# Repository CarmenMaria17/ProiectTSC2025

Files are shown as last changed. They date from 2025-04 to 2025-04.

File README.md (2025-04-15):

# TSC2025 Project

## Block Diagram



## Brief Description

### Microcontroller
- **ESP32-C6**: Main processor with WiFi/BLE, controls all components

### Display and Storage
- **E-Ink Display**: Minimal power consumption display
- **SD Card**: Electronic book storage
- **64MB Flash Memory**: For firmware and cache

### Power
- **USB-C**: Charging and data transfer
- **Battery charging circuit**: MCP73831 for LiPo battery
- **LiPo Battery**: 3.7V portable power
- **3.3V Regulator**: Voltage stabilizer for ESP32 and sensors

### Sensors
- **BME680**: Temperature and humidity, I2C connection

### Other Components
- **RTC DS3231**: Real-time clock for timekeeping
- **Buttons**: Navigation and control via GPIO

### Interfaces
- **SPI**: Display, SD card, flash memory
- **I2C**: Sensors, RTC
- **GPIO**: Buttons and control

## ESP32-C6 - Pin Allocation

### Communication pins
- **SPI_CLK**: Clock for SPI interface (connected to Flash, SD Card, Display)
- **SPI_MOSI**: Master Out Slave In for SPI
- **SPI_MISO**: Master In Slave Out for SPI
- **SS_SD**: Chip Select for SD Card
- **SS_FLASH**: Chip Select for Flash memory
- **SS_DISP**: Chip Select for E-Ink Display
- **I2C_SCL**: Clock for I2C interface
- **I2C_SDA**: Data line for I2C
- **EPD_DC**: Data/Command for E-Ink display
- **EPD_RST**: Reset for E-Ink display
- **EPD_BUSY**: Status signal from E-Ink display

### Other specific pins
- **RTC_INT**: Interrupt from RTC module
- **VBAT**: Battery power
- **3V3**: 3.3V power
- **GND**: Ground

# Bill of Materials

| Component | Model | Datasheet |
|---|---|---|
| BD5229G-TR | [Model](https://www.digikey.ee/en/models/658502) | [Datasheet](https://www.rohm.com/datasheet?p=BD5229G&dist=Digi-key&media=referral&source=digi-key.com&campaign=Digi-key) |
| ESP32 WROVER 0805 Capacitor | [Model](https://ro.mouser.com/ProductDetail/KYOCERA-AVX/SD0805S020S1R0?qs=jCA%252BPfw4LHbpkAoSnwrdjw%3D%3D) | [Datasheet](https://ro.mouser.com/datasheet/2/40/schottky-3165252.pdf) |
| 112A-TAAR-R03 | [Model](https://www.snapeda.com/parts/112A-TAAR-R03/Attend/view-part/) | [Datasheet](https://www.snapeda.com/parts/112A-TAAR-R03/Attend/datasheet/) |
| 744043680 | [Model](https://ro.mouser.com/ProductDetail/Wurth-Elektronik/744043680?qs=PGXP4M47uW6VkZq%252BkzjrHA%3D%3D) | [Datasheet](https://www.we-online.com/components/products/datasheet/744043680.pdf) |
| LED Chip 0603 | [Model](https://grabcad.com/library/0603-smd-led-1) | [Datasheet](https://www.snapeda.com/parts/KP-1608SURCK/Kingbright/datasheet/) |
| MAX17048G+T10 | [Model](https://www.snapeda.com/parts/MAX17048G+T10/Analog+Devices/view-part/?ref=eda) | [Datasheet](https://www.snapeda.com/parts/MAX17048G+T10/Analog%20Devices/datasheet/) |
| MBR0530 Schottky Diode | [Model](https://www.snapeda.com/parts/MBR0530/Onsemi/view-part/?ref=eda) | [Datasheet](https://www.snapeda.com/parts/MBR0530/ON%20Semiconductor/datasheet/) |
| PGB1010603MR | [Model](https://www.snapeda.com/parts/PGB1010603MR/Littelfuse/view-part/?ref=eda) | [Datasheet](https://www.snapeda.com/parts/PGB1010603MR/Littelfuse%20Inc./datasheet/) |
| QWIIC Connector | [Model](https://www.snapeda.com/parts/PRT-14417/SparkFun/view-part/) | [Datasheet](https://www.snapeda.com/parts/PRT-14417/SparkFun%20Electronics/datasheet/) |
| ESP32 WROVER BME680 Sensor | [Model](https://www.digikey.ro/en/models/7401317) | [Datasheet](https://www.bosch-sensortec.com/media/boschsensortec/downloads/datasheets/bst-bme680-ds001.pdf) |
| FH34SRJ-24S-0.5SH | [Model](https://www.snapeda.com/parts/FH34SRJ-24S-0.5SH(99)/Hirose/view-part/) | [Datasheet](https://www.snapeda.com/parts/FH34SRJ-24S-0.5SH(99)/Hirose%20Connector/datasheet/) |
| Resistor 0402 | [Model](https://componentsearchengine.com/part-view/R0402%201%25%20100%20K%20(RC0402FR-07100KL)/YAGEO) | [Datasheet](https://www.yageo.com/upload/media/product/products/datasheet/rchip/PYu-RC_Group_51_RoHS_L_12.pdf) |
| ESP32 WROVER MCP73831 Power Management | [Model](https://www.snapeda.com/parts/MCP73831T-2ACI/OT/Microchip/view-part/) | [Datasheet](https://www.snapeda.com/parts/MCP73831T-2ACI/OT/Microchip/datasheet/) |
| ESP32C6 Varistor 1812 | [Model](https://www.snapeda.com/parts/RC0603JR-070RL/Yageo/view-part/) | [Datasheet](https://www.snapeda.com/parts/RC0603JR-070RL/Yageo/datasheet/) |
| ESP32C6 WROOM-1-N8 | [Model](https://www.snapeda.com/parts/ESP32-C6-WROOM-1-N8/Espressif+Systems/view-part/?ref=eda) | [Datasheet](https://www.snapeda.com/parts/ESP32-C6-WROOM-1-N8/Espressif%20Systems/datasheet/) |
| Capacitor 0402 | [Model](https://componentsearchengine.com/part-view/CC0402MRX5R5BB106/YAGEO) | [Datasheet](https://componentsearchengine.com/Datasheets/2/CC0402MRX5R5BB106.pdf) |
| SI1308EDL-T1-GE3 MOSFET | [Model](https://www.snapeda.com/parts/SI1308EDL-T1-GE3/Vishay+Siliconix/view-part/?ref=eda) | [Datasheet](https://www.snapeda.com/parts/SI1308EDL-T1-GE3/Vishay%20Siliconix/datasheet/) |
| SJ | [Model](https://grabcad.com/library/solder-jumpers-1) | [Datasheet]() |
| CPH3225A | [Model](https://www.snapeda.com/parts/CPH3225A/Seiko+Instruments/view-part/?ref=eda) | [Datasheet](https://www.snapeda.com/parts/CPH3225A/Seiko%20Instruments/datasheet/) |
| Button | [Model](https://industry.panasonic.com/global/en/products/control/switch/light-touch/number/evqpuj02k) | [Datasheet](https://industry.panasonic.com/global/en/downloads?tab=catalog&small_g_cd=203&part_no=EVQPUJ02K) |
| DS3231SN | [Model](https://www.snapeda.com/parts/DS3231SN%23/Analog+Devices/view-part/?ref=eda) | [Datasheet](https://www.snapeda.com/parts/DS3231SN%23/Analog%20Devices/datasheet/) |
| USBLC6-2SC6Y | [Model](https://www.snapeda.com/parts/USBLC6-2SC6Y/STMicroelectronics/view-part/?ref=eda) | [Datasheet](https://www.snapeda.com/parts/USBLC6-2SC6Y/STMicroelectronics/datasheet/) |
| W25Q512JVEIQ | [Model](https://www.digikey.ro/en/models/10244706) | [Datasheet](https://www.winbond.com/resource-files/W25Q512JV%20SPI%20RevB%2006252019%20KMS.pdf) |
| XC6220A331MR-G | [Model](https://componentsearchengine.com/part-view/XC6220A331MR-G/Torex) | [Datasheet](https://product.torexsemi.com/system/files/series/xc6220.pdf) |
| TPTP20R | [Model](https://ro.mouser.com/ProductDetail/Adafruit/3825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) | [Datasheet](https://cdn-shop.adafruit.com/product-files/3825/3825_diagram.PDF) |
| USB4110-GF-A | [Model](https://componentsearchengine.com/part-view/USB4110-GF-A/GCT%20(GLOBAL%20CONNECTOR%20TECHNOLOGY)) | [Datasheet](https://gct.co/files/drawings/usb4110.pdf) |

# Power Consumption Estimation

The ESP32-C6 microcontroller with Wi-Fi active draws approximately 200mA at 3.3V, consuming around 660mW of power.

For display operations, the 1.5" E-Ink display requires about 40mA (132mW) during refresh cycles.

The BME680 environmental sensor consumes minimal power at just 3.1mA (10.23mW) during measurement operations and can be put into sleep mode between readings.

The DS3231 RTC module is extremely efficient, drawing only 0.15mA (0.495mW) while maintaining accurate timekeeping.

Storage components include the SD card for e-book storage that requires 50mA (165mW) during active read/write operations, and the 64MB external flash memory that draws about 25mA (82.5mW) when accessed.

In total, the maximum estimated power consumption is approximately 318.25mA at 3.3V, resulting in 1050.72mW during peak usage.

# Other images




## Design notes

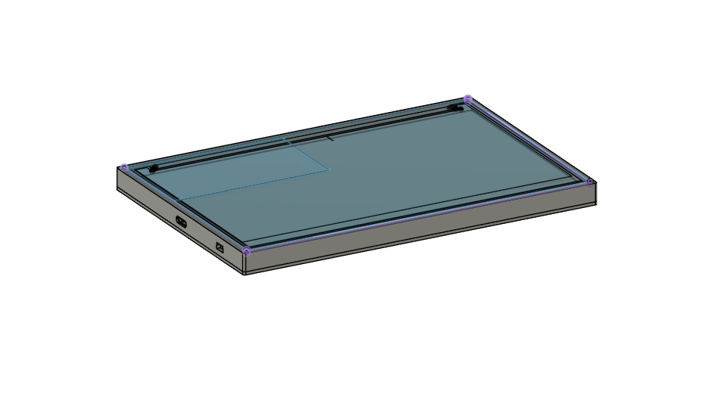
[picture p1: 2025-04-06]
Images/Screenshot 2025-04-06 194232.png

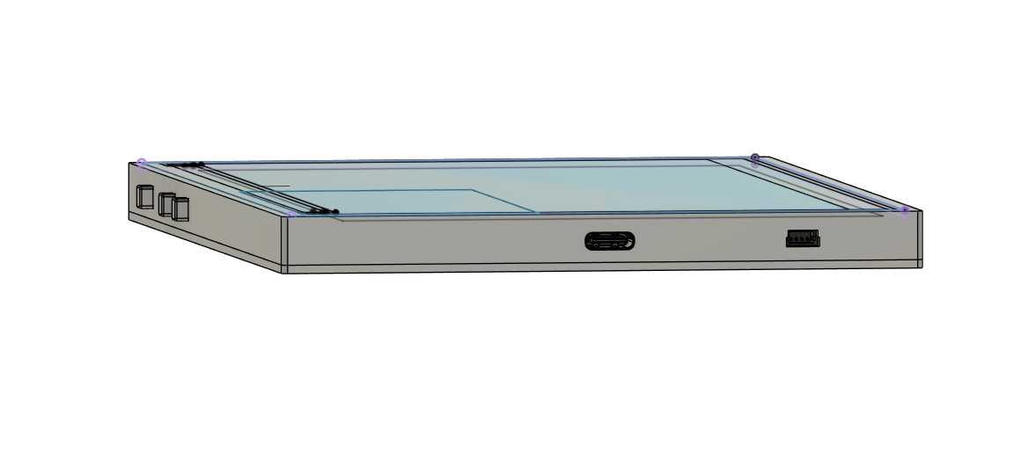
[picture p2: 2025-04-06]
Images/Screenshot 2025-04-06 194247.png

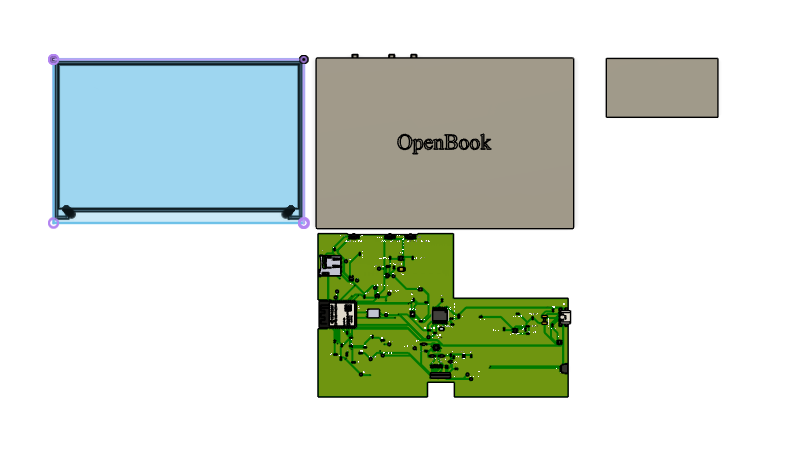
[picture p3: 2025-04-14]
Images/Screenshot 2025-04-15 002725.png

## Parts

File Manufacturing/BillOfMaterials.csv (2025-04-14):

Qty | Value | Device | Package | Parts | Description | ARROW_PART_NUMBER | ARROW_PRICE-STOCK | AVAILABILITY | CENTROID_NOT_SPECIFIED | CHECK_PRICES | COPYRIGHT | DATASHEET | DESCRIPTION | DIGIKEY_DESCRIPTION | DIGIKEY_PART_NUMBER | HEIGHT | LEAD_FREE | MANUFACTURER_NAME | MANUFACTURER_PART_NUMBER | MF | MFR_NAME | MOUSER_PART_NUMBER | MOUSER_PRICE-STOCK | MOUSER_TESTING_PART_NUMBER | MOUSER_TESTING_PRICE-STOCK | MP | MPN | PACKAGE | POPULARITY | PREFIX | PRICE | PROD_ID | PURCHASE-URL | ROHS | SNAPEDA_LINK | SPICEMODEL | SPICEPREFIX | TEMPERATURE_RANGE_HIGH | TEMPERATURE_RANGE_LOW | TP_SIGNAL_NAME | VALUE | LSCS Part number
1 |  | ADAFRUIT_LEDCHIP-LED0603 | ADAFRUIT_CHIP-LED0603 | CHG_LED | LED
1 |  | ESP32_WROVER_EAGLE-LTSPICE_RR0402 | ESP32_WROVER_EAGLE-LTSPICE_R0402 | R2 | RESISTOR, European symbol |  |  |  |  |  |  |  |  |  |  |  |  |  |  |  |  |  |  |  |  |  |  |  |  |  |  |  |  |  |  | NONE | R
1 |  | SJ | SJ | SJ1 | SMD solder JUMPER |  |  |  |  |  |  |  |  |  |  |  |  |  |  |  |  |  |  |  |  |  |  |  | 3
1 | 0.47 | ESP32_WROVER_EAGLE-LTSPICE_RR0402 | ESP32_WROVER_EAGLE-LTSPICE_R0402 | R3 | RESISTOR, European symbol |  |  |  |  |  |  |  |  |  |  |  |  |  |  |  |  |  |  |  |  |  |  |  |  |  |  |  |  |  |  | NONE | R
1 | 100k | ESP32_WROVER_EAGLE-LTSPICE_RR0402 | ESP32_WROVER_EAGLE-LTSPICE_R0402 | R1_PWRUSB | RESISTOR, European symbol |  |  |  |  |  |  |  |  |  |  |  |  |  |  |  |  |  |  |  |  |  |  |  |  |  |  |  |  |  |  | NONE | R
8 | 100nF | EAGLE-LTSPICE_CC0402 | EAGLE-LTSPICE_C0402 | C1, C2, C4_USB, C6, C8, C9, C10, C_DELAY | CAPACITOR, European symbol |  |  |  |  |  |  |  |  |  |  |  |  |  |  |  |  |  |  |  |  |  |  |  |  |  |  |  |  |  |  | NONE | C
1 | 100uF TANT | RCL_CPOL-EUCT3528 | RCL_CT3528 | C3 | POLARIZED CAPACITOR, European symbol |  |  |  |  |  |  |  |  |  |  |  |  |  |  |  |  |  |  |  |  |  |  |  | 0 |  |  |  |  |  |  |  | C
10 | 10K | ESP32_WROVER_EAGLE-LTSPICE_RR0402 | ESP32_WROVER_EAGLE-LTSPICE_R0402 | R1_PINH, R2-PINH, R5, R6, R7, R8, R9, R10, R_CHANGE, R_CL1 | RESISTOR, European symbol |  |  |  |  |  |  |  |  |  |  |  |  |  |  |  |  |  |  |  |  |  |  |  |  |  |  |  |  |  |  | NONE | R
6 | 10k | ESP32_WROVER_EAGLE-LTSPICE_RR0402 | ESP32_WROVER_EAGLE-LTSPICE_R0402 | R1, R1_PINH1, R2-PINH1, R4, R_BOOT, R_RESET | RESISTOR, European symbol |  |  |  |  |  |  |  |  |  |  |  |  |  |  |  |  |  |  |  |  |  |  |  |  |  |  |  |  |  |  | NONE | R
1 | 10uF | EAGLE-LTSPICE_CC0402 | EAGLE-LTSPICE_C0402 | C7 | CAPACITOR, European symbol |  |  |  |  |  |  |  |  |  |  |  |  |  |  |  |  |  |  |  |  |  |  |  |  |  |  |  |  |  |  | NONE | C
1 | 112A-TAAR-R03_ATTEND | 112A-TAAR-R03_ATTEND | 112ATAARR03ATTEND | J4 | Micro SD Card Socket, Push-Push Type, Top Mount, SMT, H=1.83mm, 10u |  |  |  |  |  |  |  | Micro SD Card Socket | Push-Push Type | Top Mount | SMT | H=1.83mm | 10u |  |  | 1.9mm |  | ATTEND | 112A-TAAR-R03 ATTEND
1 | 15 | ESP32_WROVER_EAGLE-LTSPICE_RR0402 | ESP32_WROVER_EAGLE-LTSPICE_R0402 | R_CAPACITOR | RESISTOR, European symbol |  |  |  |  |  |  |  |  |  |  |  |  |  |  |  |  |  |  |  |  |  |  |  |  |  |  |  |  |  |  | NONE | R
1 | 1uF | EAGLE-LTSPICE_CC0402 | EAGLE-LTSPICE_C0402 | C5 | CAPACITOR, European symbol |  |  |  |  |  |  |  |  |  |  |  |  |  |  |  |  |  |  |  |  |  |  |  |  |  |  |  |  |  |  | NONE | C
10 | 1uF/50V | EAGLE-LTSPICE_CC0402 | EAGLE-LTSPICE_C0402 | EPD_C1, EPD_C2, EPD_C5, EPD_C6, EPD_C7, EPD_C8, EPD_C9, EPD_C10, EPD_C11, EPD_C12 | CAPACITOR, European symbol |  |  |  |  |  |  |  |  |  |  |  |  |  |  |  |  |  |  |  |  |  |  |  |  |  |  |  |  |  |  | NONE | C
1 | 200 | ESP32_WROVER_EAGLE-LTSPICE_RR0402 | ESP32_WROVER_EAGLE-LTSPICE_R0402 | R1_BAT | RESISTOR, European symbol |  |  |  |  |  |  |  |  |  |  |  |  |  |  |  |  |  |  |  |  |  |  |  |  |  |  |  |  |  |  | NONE | R
2 | 20V/4.2A/52mO/1.4W | ESP32_WROVER_SPARKFUN-DISCRETESEMI_MOSFET_PCH-DMG2305UX-7 | ESP32_WROVER_SPARKFUN-DISCRETESEMI_SOT23-3 | Q1, Q2 | P-channel MOSFETs |  |  |  |  |  |  |  |  |  |  |  |  |  |  |  |  |  |  |  |  |  |  |  |  |  |  | TRAN-14388 |  |  |  |  |  |  |  |  | 20V/4.2A/52mO/1.4W
1 | 2K | ESP32_WROVER_EAGLE-LTSPICE_RR0402 | ESP32_WROVER_EAGLE-LTSPICE_R0402 | R2_BAT | RESISTOR, European symbol |  |  |  |  |  |  |  |  |  |  |  |  |  |  |  |  |  |  |  |  |  |  |  |  |  |  |  |  |  |  | NONE | R
1 | 4.7uF | EAGLE-LTSPICE_CC0402 | EAGLE-LTSPICE_C0402 | C5_USB | CAPACITOR, European symbol |  |  |  |  |  |  |  |  |  |  |  |  |  |  |  |  |  |  |  |  |  |  |  |  |  |  |  |  |  |  | NONE | C
4 | 47uF | EAGLE-LTSPICE_CC0402 | EAGLE-LTSPICE_C0402 | C1_BAT, C1_BAT1, C1_BAT2, C2_BAT | CAPACITOR, European symbol |  |  |  |  |  |  |  |  |  |  |  |  |  |  |  |  |  |  |  |  |  |  |  |  |  |  |  |  |  |  | NONE | C
1 | 47uF/25V | EAGLE-LTSPICE_CC0402 | EAGLE-LTSPICE_C0402 | C4 | CAPACITOR, European symbol |  |  |  |  |  |  |  |  |  |  |  |  |  |  |  |  |  |  |  |  |  |  |  |  |  |  |  |  |  |  | NONE | C
2 | 5k1 | ESP32_WROVER_EAGLE-LTSPICE_RR0402 | ESP32_WROVER_EAGLE-LTSPICE_R0402 | R2-USB, R2-USB1 | RESISTOR, European symbol |  |  |  |  |  |  |  |  |  |  |  |  |  |  |  |  |  |  |  |  |  |  |  |  |  |  |  |  |  |  | NONE | R
1 | 68uH | 744043680IND_4828-WE-TPC_WRE | IND_4828-WE-TPC_WRE | L1 |  |  |  |  |  |  | Copyright (C) 2024 Ultra Librarian. All rights reserved. |  |  |  |  |  |  |  | 744043680 |  | Wurth Electronics
1 | BD5229G-TR | BD5229G-TR | SOT95P280X125-5N | IC1 | Voltage Detector with Adjustable Delay Time: CMOS processes are utilized to develop high precision, low current consumption CMOS reset ICs that allow arbitrary setting of the delay time. The extensive lineup includes both Nch Open Drain and CMOS output types in a wide range of detection voltages (from 2.3V to 6.0V, in 0.1V steps), enabling selection of the ideal solution based on customer requirements. In addition, the entire series is of course both lead-free and RoHS-compliant. |  |  |  |  |  |  |  | Voltage Detector with Adjustable Delay Time: CMOS processes are utilized to develop high precision | low current consumption CMOS reset ICs that allow arbitrary setting of the delay time. The extensive lineup includes both Nch Open Drain and CMOS output types in a wide range of detection voltages (from 2.3V to 6.0V | in 0.1V steps) | enabling selection of the ideal solution based on customer requirements. In addition | the entire series is of course both lead-free and RoHS-compliant. |  |  | 1.25mm |  | ROHM Semiconductor | BD5229G-TR |  |  | 755-BD5229G-TR | https://www.mouser.co.uk/ProductDetail/ROHM-Semiconductor/BD5229G-TR?qs=4kLU8WoGk0vvnhrrYwdszw%3D%3D
1 | BME688 | ESP32_WROVER_BME680_BME680 | ESP32_WROVER_BME680_PSON80P300X300X100-8N | SENSOR2 | Integrated Environmental Unit |  |  | Unavailable |  |  |  |  | Integrated Environmental Unit |  |  |  |  |  |  | Bosch Sensortec |  |  |  |  |  | BME680 |  | LGA-8 Bosch Tools |  |  | None
3 | BUTTON_CUSYOMV1 | BUTTON_CUSYOMV1 | MYBUTTON | BOOT_BUTTON, CHANGE_BUTTON, RESET_BUTTON
1 | CPH3225A | CPH3225A | CAPCP3225X100N | C10_SUPERCAP | Cap 0.011F 3.3V 1210 Flat Check availability |  |  | Not in stock |  | https://www.snapeda.com/parts/CPH3225A/Seiko+Instruments/view-part/?ref=eda |  |  | 11 mF (EDLC) Supercapacitor 3.3 V 1210 (3225 Metric) - - |  |  |  |  |  |  | Seiko Instruments |  |  |  |  |  | CPH3225A |  | 1210 Seiko |  |  | None |  | https://www.snapeda.com/api/url_track_click_mouser/?unipart_id=562593&manufacturer=Seiko Instruments&part_name=CPH3225A&search_term=None |  | https://www.snapeda.com/parts/CPH3225A/Seiko+Instruments/view-part/?ref=snap
1 | DS3231SN# | DS3231SN# | SOIC127P1032X265-16N | U3 | Real Time Clock Serial 16-Pin SOIC W T/R Check availability |  |  | In Stock |  | https://www.snapeda.com/parts/DS3231SN%23/Analog+Devices/view-part/?ref=eda |  |  | Extremely Accurate I²C-Integrated RTC/TCXO/Crystal |  |  |  |  |  |  | Analog Devices |  |  |  |  |  | DS3231SN# |  | SOIC-16 Maxim |  |  | None |  | https://www.snapeda.com/api/url_track_click_mouser/?unipart_id=99048&manufacturer=Analog Devices&part_name=DS3231SN#&search_term=None |  | https://www.snapeda.com/parts/DS3231SN%23/Analog+Devices/view-part/?ref=snap
1 | ESP32-C6-WROOM-1-N8 | ESP32-C6-WROOM-1-N8 | XCVR_ESP32-C6-WROOM-1-N8 | U2 | Check availability |  |  | In Stock |  | https://www.snapeda.com/parts/ESP32-C6-WROOM-1-N8/Espressif+Systems/view-part/?ref=eda |  |  | Multiprotocol Modules ESP32-C6 module | Wi-Fi 6 in 2.4 GHz band | Bluetooth 5 | Zigbee 3.0 and Thread. ESP34-WROOM Compatible - ENGINEERING SAMPLE |  |  |  |  |  |  | Espressif Systems |  |  |  |  |  | ESP32-C6-WROOM-1-N8 |  | None |  |  | None |  |  |  | https://www.snapeda.com/parts/ESP32-C6-WROOM-1-N8/Espressif+Systems/view-part/?ref=snap
1 | ESP32C6_VARISTORCN1812 | ESP32C6_VARISTORCN1812 | ESP32C6_VARISTOR_CT/CN1812 | PFMF.050.1 | VARISTOR |  |  |  |  |  |  |  |  |  |  |  |  |  |  |  |  |  |  |  |  |  |  |  | 0
1 | ESP32_WROVER_SPARKFUN-IC-POWER_MCP73831 | ESP32_WROVER_SPARKFUN-IC-POWER_MCP73831 | ESP32_WROVER_SPARKFUN-IC-POWER_SOT23-5 | MCP73831 | MCP73831T Li-Ion, Li-Pol Controller |  |  |  |  |  |  |  |  |  |  |  |  |  |  |  |  |  |  |  |  |  |  |  |  |  |  | IC-09995
1 | FH34SRJ-24S-0.5SH_99_ | FH34SRJ-24S-0.5SH_99_ | FH34SRJ24S05SH99 | J1 | (0.50mm) Surface Mount, Right Angle |  |  |  |  |  |  |  | 24 Position FFC | FPC Connector Contacts | (0.50mm) Surface Mount | Right Angle |  |  | 1.1mm |  | Hirose | FH34SRJ-24S-0.5SH(99) |  |  | 798-FH34SRJ24S05SH99 | https://www.mouser.co.uk/ProductDetail/Hirose-Connector/FH34SRJ-24S-0.5SH99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
1 | MAX17048G+T10 | MAX17048G+T10 | SON50P200X200X80-9N | U4 | Check availability |  |  | In Stock |  | https://www.snapeda.com/parts/MAX17048G+T10/Analog+Devices/view-part/?ref=eda |  |  | 3µA 1-Cell/2-Cell Fuel Gauge with ModelGauge |  |  |  |  |  |  | Analog Devices |  |  |  |  |  | MAX17048G+T10 |  | TDFN-8 Maxim |  |  | None |  | https://www.snapeda.com/api/url_track_click_mouser/?unipart_id=329239&manufacturer=Analog Devices&part_name=MAX17048G+T10&search_term=None |  | https://www.snapeda.com/parts/MAX17048G+T10/Analog+Devices/view-part/?ref=snap
3 | MBR0530 | MBR0530 | SOD3716X135N | D3, D4, D5 | ON SEMICONDUCTOR - MBR0530 - DIODE, SCHOTTKY, 0.5A, 30V, SOD-123 |  |  | In Stock |  | https://www.snapeda.com/parts/MBR0530/Onsemi/view-part/?ref=eda |  |  | Diode Schottky 30 V 500mA Surface Mount SOD-123 |  |  |  |  |  |  | ON Semiconductor |  |  |  |  |  | MBR0530 |  | SOD-123-2 ON Semiconductor |  |  | None |  | https://www.snapeda.com/api/url_track_click_mouser/?unipart_id=179458&manufacturer=ON Semiconductor&part_name=MBR0530&search_term=None |  | https://www.snapeda.com/parts/MBR0530/Onsemi/view-part/?ref=snap
6 | PGB1010603MR | PGB1010603MR | DIOC1608X36N | D6, D8, D9, D10, D11, D12 | Check availability |  |  | In Stock |  | https://www.snapeda.com/parts/PGB1010603MR/Littelfuse/view-part/?ref=eda |  |  | 150V (Typ) Clamp - Ipp Tvs Diode Surface Mount 0603 (1608 Metric) |  |  |  |  |  |  | Littelfuse Inc. |  |  |  |  |  | PGB1010603MR |  | 0603 Littelfuse Inc. |  |  | None |  | https://www.snapeda.com/api/url_track_click_mouser/?unipart_id=5659453&manufacturer=Littelfuse Inc.&part_name=PGB1010603MR&search_term=None |  | https://www.snapeda.com/parts/PGB1010603MR/Littelfuse/view-part/?ref=snap
1 | QWIIC_RIGHT_ANGLE | QWIIC_CONNECTORJS-1MM | JST04_1MM_RA | J3 | SparkFun I2C Standard Qwiic Connector |  |  |  |  |  |  |  |  |  |  |  |  |  |  |  |  |  |  |  |  |  |  |  |  |  |  | CONN-13694 |  |  |  |  |  |  |  |  | QWIIC_RIGHT_ANGLE
1 | SAMACSYS_PARTS_USB4110-GF-A | SAMACSYS_PARTS_USB4110-GF-ASAM | SAMACSYS_PARTS_USB4110GFA | J2 | CONN USB 2.0 TYPE-C R/A SMT
2 | SD0805S020S1R0 | ESP32_WROVER_AVX---SD0805S020S1R0_AVX_SD0805S020S1R0_0_0AVX_SD0805S020S1R0_0_0 | ESP32_WROVER_AVX---SD0805S020S1R0_AVX_SD0805S020S1R0_0 | D2, D7 | Schottky Barrier Rectifier Diode |  |  |  | No |  |  | http://datasheets.avx.com/schottky.pdf |  | DIODE SCHOTTKY 20V 1A 0805 | 478-7800-1-ND |  | yes |  |  | AVX |  | 581-SD0805S020S1R0 |  |  |  |  |  | 0805 (2012 metric) |  | D |  |  |  | yes |  |  |  | +125°C | -55°C
1 | SI1308EDL-T1-GE3 | SI1308EDL-T1-GE3 | SOT65P210X110-3N | Q3 | MOSFET N-Ch 30V 1.5A TrenchFET SC70 Vishay Si1308EDL-T1-GE3 N-channel MOSFET Transistor, 1.5 A, 30 V, 3-Pin SC-70 |  |  | In Stock |  | https://www.snapeda.com/parts/SI1308EDL-T1-GE3/Vishay+Siliconix/view-part/?ref=eda |  |  | Si1308EDL-T1-GE3 N-channel MOSFET Transistor | 1.5 A | 30 V | 3-Pin SC-70 | Siliconix / Vishay SI1308EDL-T1-GE3 |  |  |  |  |  |  | Vishay Siliconix |  |  |  |  |  | SI1308EDL-T1-GE3 |  | SOT-323 Vishay Semiconductor |  |  | None |  | https://www.snapeda.com/api/url_track_click_mouser/?unipart_id=274603&manufacturer=Vishay Siliconix&part_name=SI1308EDL-T1-GE3&search_term=None |  | https://www.snapeda.com/parts/SI1308EDL-T1-GE3/Vishay+Siliconix/view-part/?ref=snap
17 | TPTP20R | TPTP20R | TP20R | TP1, TP2, TP3, TP4, TP5, TP6, TP7, TP8, TP9, TP10, TP11, TP12, TP13, TP14, TP15, TP16, TP17 | Test pad |  |  |  |  |  |  |  |  |  |  |  |  |  |  |  |  |  |  |  |  |  |  |  | 2
1 | USBLC6-2SC6Y | USBLC6-2SC6Y | SOT95P280X145-6N | D1 | Low Cap. ESD Protection Auto SOT-23-6 STMicroelectronics USBLC6-2SC6Y, Dual Uni-Directional TVS Diode Array, 6-Pin SOT-23 |  |  | In Stock |  | https://www.snapeda.com/parts/USBLC6-2SC6Y/STMicroelectronics/view-part/?ref=eda |  |  | 17V Clamp 5A (8/20µs) Ipp Tvs Diode Surface Mount SOT-23-6 |  |  |  |  |  |  | STMicroelectronics |  |  |  |  |  | USBLC6-2SC6Y |  | SOT-23-6 STMicroelectronics |  |  | None |  |  |  | https://www.snapeda.com/parts/USBLC6-2SC6Y/STMicroelectronics/view-part/?ref=snap
1 | W25Q512JVEIQ | W25Q512JVEIQ | SON127P600X800X80-9N | U1 | Check availability |  |  | In Stock |  | https://www.snapeda.com/parts/W25Q512JVEIQ/Winbond+Electronics/view-part/?ref=eda |  |  | FLASH - NOR Memory IC 512Mb (64M x 8) SPI - Quad I/O 133 MHz 8-WSON (8x6) |  |  |  |  |  |  | Winbond Electronics |  |  |  |  |  | W25Q512JVEIQ |  | Package |  |  | None |  |  |  | https://www.snapeda.com/parts/W25Q512JVEIQ/Winbond+Electronics/view-part/?ref=snap
1 | XC6220A331MR-G | XC6220A331MR-G | SOT95P280X120-5N | IC4 | LDO Voltage Regulators |  |  |  |  |  |  |  | LDO Voltage Regulators |  |  | 1.2mm |  | Torex | XC6220A331MR-G |  |  | 865-XC6220A331MR-G | https://www.mouser.co.uk/ProductDetail/Torex-Semiconductor/XC6220A331MR-G?qs=AsjdqWjXhJ8ZSWznL1J0gg%3D%3D

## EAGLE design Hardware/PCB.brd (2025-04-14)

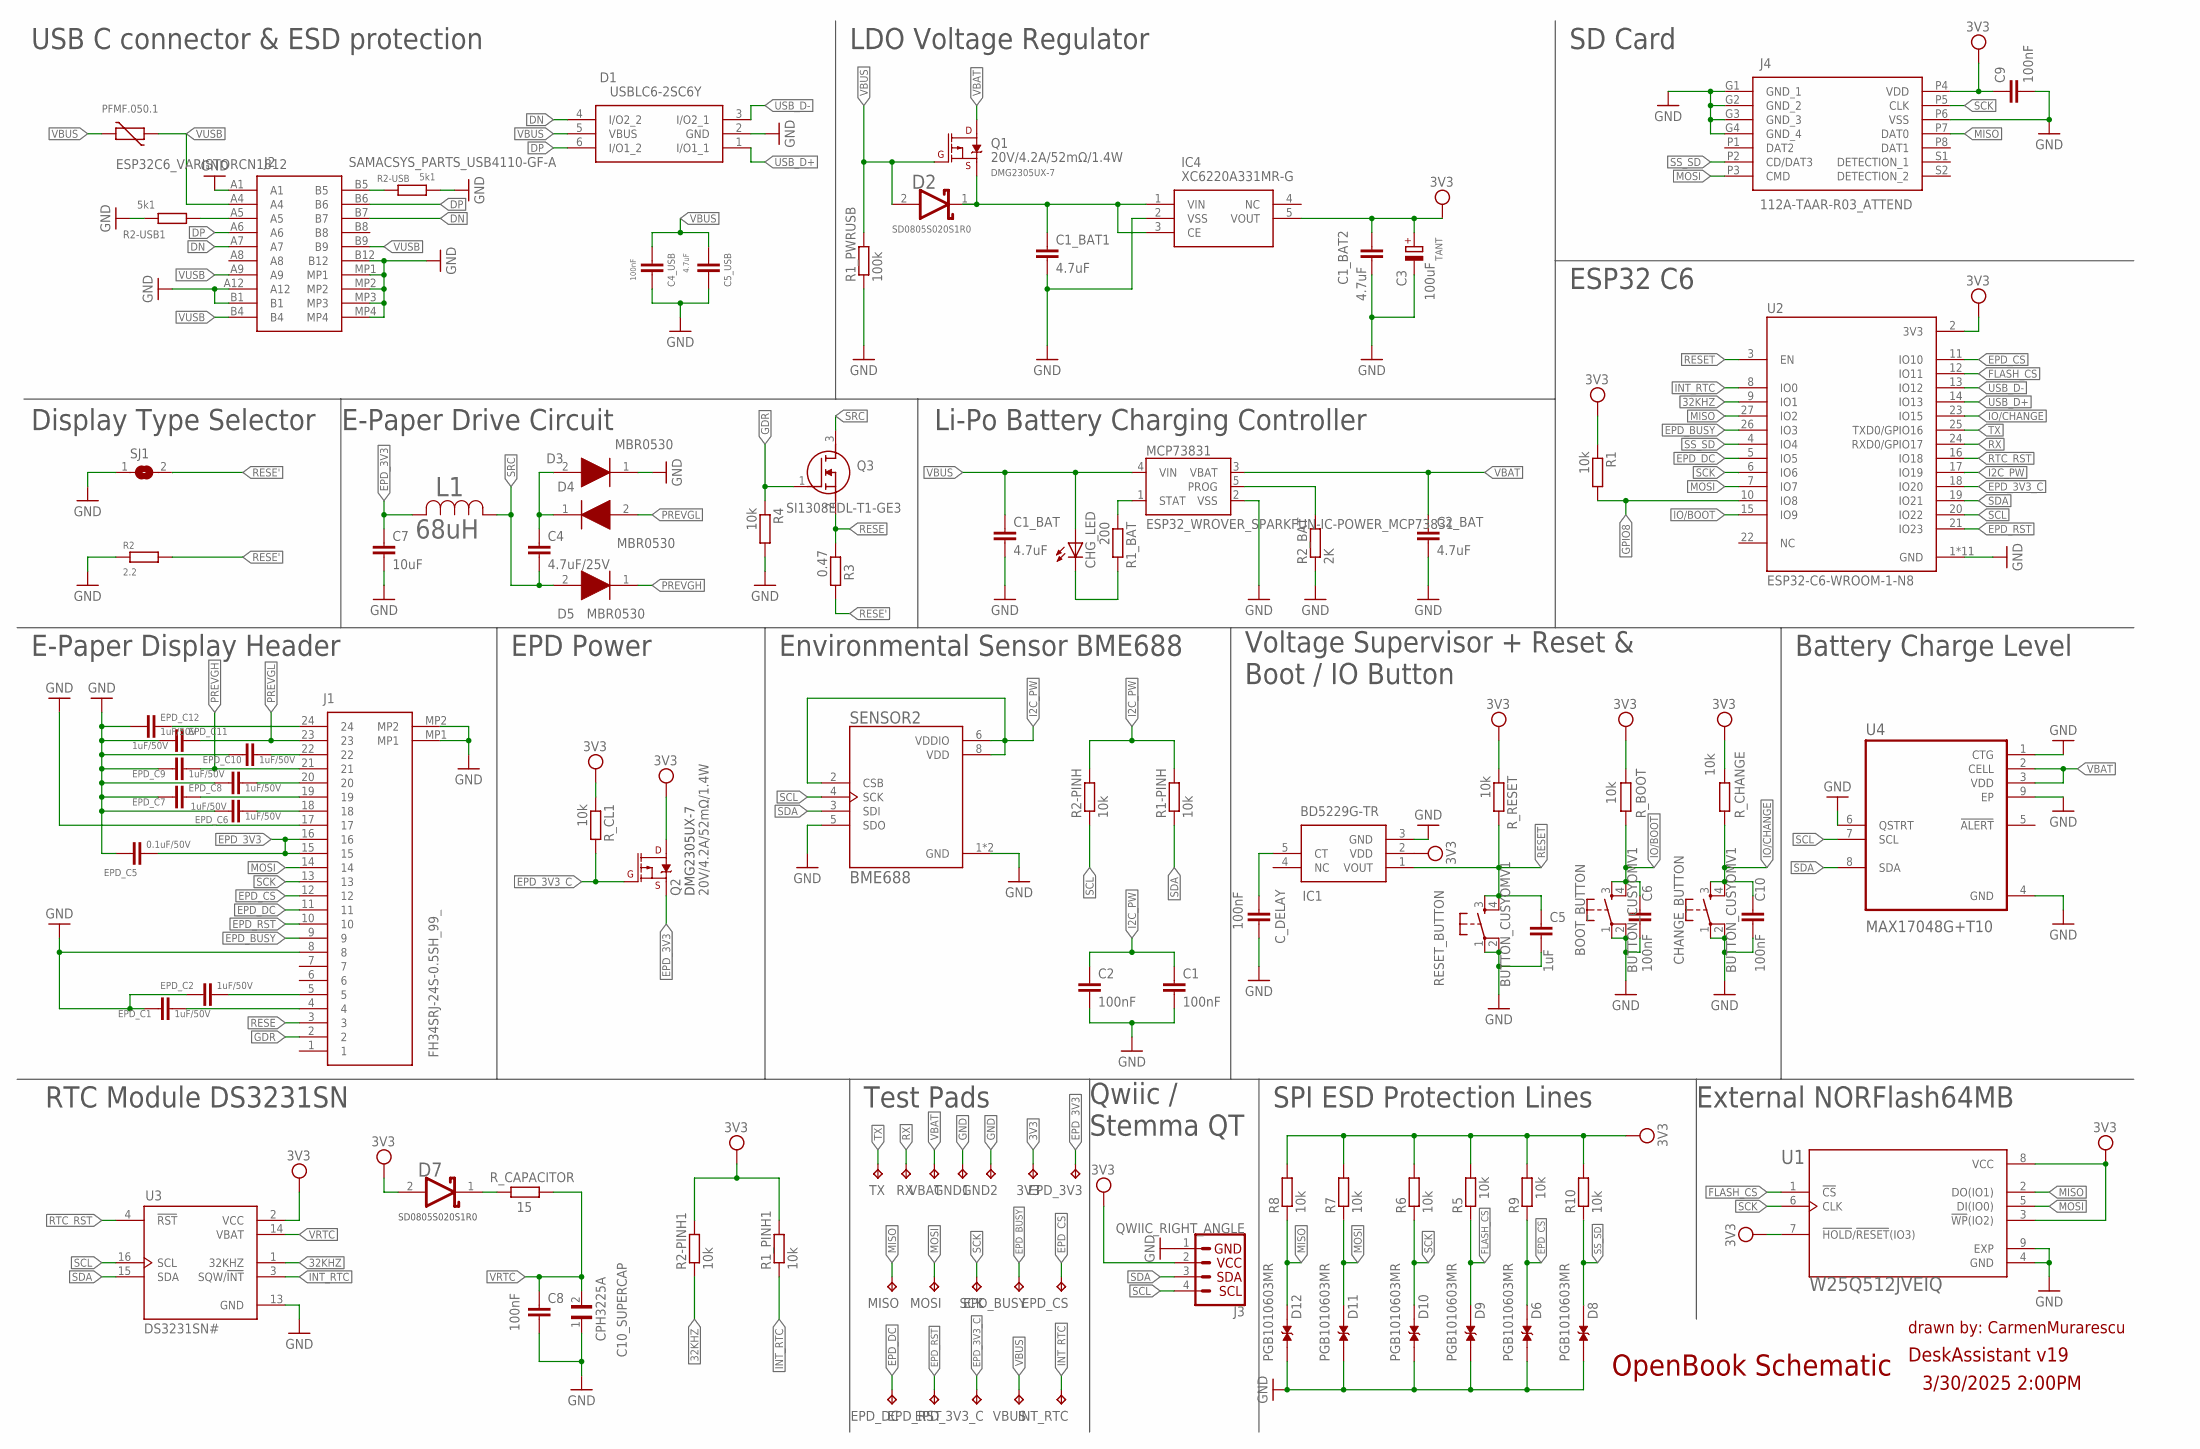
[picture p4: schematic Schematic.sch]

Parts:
3V3: TPTP20R; TP20R
BOOT_BUTTON: BUTTON_CUSYOMV1; MYBUTTON
C1, C2, C4_USB, C6, C8, C9, C10: 100nF; ESP32_WROVER_EAGLE-LTSPICE_C0402
C1_BAT, C1_BAT1, C1_BAT2, C2_BAT, C5_USB: 4.7uF; ESP32_WROVER_EAGLE-LTSPICE_C0402
C3: 100uF; RCL_CT3528
C4: 4.7uF/25V; ESP32_WROVER_EAGLE-LTSPICE_C0402
C5: 1uF; ESP32_WROVER_EAGLE-LTSPICE_C0402
C7: 10uF; ESP32_WROVER_EAGLE-LTSPICE_C0402
C10_SUPERCAP: CPH3225A; CAPCP3225X100N
CHANGE_BUTTON: BUTTON_CUSYOMV1; MYBUTTON
CHG_LED: ADAFRUIT_LEDCHIP-LED0603; ADAFRUIT_CHIP-LED0603
C_DELAY: 100nF; ESP32_WROVER_EAGLE-LTSPICE_C0402
D1: USBLC6-2SC6Y; SOT95P280X145-6N
D2: ESP32_WROVER_AVX---SD0805S020S1R0_AVX_SD0805S020S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; ESP32_WROVER_AVX---SD0805S020S1R0_AVX_SD0805S020S1R0_0
D3, D4, D5: MBR0530; SOD3716X135N
D6, D8, D9, D10, D11, D12: PGB1010603MR; DIOC1608X36N
D7: SD0805S020S1R0; ESP32_WROVER_AVX---SD0805S020S1R0_AVX_SD0805S020S1R0_0
EPD_3V3, EPD_3V3_C: TPTP20R; TP20R
EPD_BUSY: TPTP20R; TP20R
EPD_C1, EPD_C2, EPD_C6, EPD_C7, EPD_C8, EPD_C9, EPD_C10, EPD_C11, EPD_C12: 1uF/50V; ESP32_WROVER_EAGLE-LTSPICE_C0402
EPD_C5: 0.1uF/50V; ESP32_WROVER_EAGLE-LTSPICE_C0402
EPD_CS: TPTP20R; TP20R
EPD_DC: TPTP20R; TP20R
EPD_RST: TPTP20R; TP20R
GND1, GND2: TPTP20R; TP20R
IC1: BD5229G-TR; SOT95P280X120-5N
IC4: XC6220A331MR-G; SOT95P280X120-5N
INT_RTC: TPTP20R; TP20R
J1: FH34SRJ-24S-0.5SH_99_; FH34SRJ24S05SH99
J2: SAMACSYS_PARTS_USB4110-GF-A; SAMACSYS_PARTS_USB4110GFA
J3: QWIIC_RIGHT_ANGLE; JST04_1MM_RA
J4: 112A-TAAR-R03_ATTEND; 112ATAARR03ATTEND
L1: 68uH; IND_4828-WE-TPC_WRE
MCP73831: ESP32_WROVER_SPARKFUN-IC-POWER_MCP73831; ESP32_WROVER_SPARKFUN-IC-POWER_SOT23-5
MISO: TPTP20R; TP20R
MOSI: TPTP20R; TP20R
PFMF.050.1: ESP32C6_VARISTORCN1812; ESP32C6_VARISTOR_CT/CN1812
Q1, Q2: 20V/4.2A/52mΩ/1.4W; ESP32_WROVER_SPARKFUN-DISCRETESEMI_SOT23-3
Q3: SI1308EDL-T1-GE3; SOT65P210X110-3N
R1, R1-PINH, R1_PINH1, R2-PINH, R2-PINH1, R4, R5, R6, R7, R8, R9, R10: 10k; ESP32_WROVER_EAGLE-LTSPICE_R0402
R1_BAT: 200; ESP32_WROVER_EAGLE-LTSPICE_R0402
R1_PWRUSB: 100k; ESP32_WROVER_EAGLE-LTSPICE_R0402
R2: 2.2; ESP32_WROVER_EAGLE-LTSPICE_R0402
R2-USB, R2-USB1: 5k1; ESP32_WROVER_EAGLE-LTSPICE_R0402
R2_BAT: 2K; ESP32_WROVER_EAGLE-LTSPICE_R0402
R3: 0.47; ESP32_WROVER_EAGLE-LTSPICE_R0402
RESET_BUTTON: BUTTON_CUSYOMV1; MYBUTTON
RX: TPTP20R; TP20R
R_BOOT: 10k; ESP32_WROVER_EAGLE-LTSPICE_R0402
R_CAPACITOR: 15; ESP32_WROVER_EAGLE-LTSPICE_R0402
R_CHANGE: 10k; ESP32_WROVER_EAGLE-LTSPICE_R0402
R_CL1: 10k; ESP32_WROVER_EAGLE-LTSPICE_R0402
R_RESET: 10k; ESP32_WROVER_EAGLE-LTSPICE_R0402
SCK: TPTP20R; TP20R
SENSOR2: BME688; ESP32_WROVER_BME680_PSON80P300X300X100-8N
SJ1: SJ
TX: TPTP20R; TP20R
U1: W25Q512JVEIQ; SON127P600X800X80-9N
U2: ESP32-C6-WROOM-1-N8; XCVR_ESP32-C6-WROOM-1-N8
U3: DS3231SN#; SOIC127P1032X265-16N
U4: MAX17048G+T10; SON50P200X200X80-9N
VBAT: TPTP20R; TP20R
VBUS: TPTP20R; TP20R

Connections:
3V3: 3V3.TP, C1_BAT2.1, C3.+, C9.1, D7.2 (ANODE), IC1.2 (VDD), IC4.5 (VOUT), J3.2, J4.P4 (VDD), Q2.3 (D), R1.1, R1_PINH1.2, R2-PINH1.2, R5.2, R6.2, R7.2, R8.2, R9.2, R10.2, R_BOOT.2, R_CHANGE.2, R_CL1.1, R_RESET.1, U1.3 (!WP!(IO2)), U1.7 (!HOLD!/!RESET!(IO3)), U1.8 (VCC), U2.2 (3V3), U3.2 (VCC)
32KHZ: R2-PINH1.1, U2.9 (IO1), U3.1 (32KHZ)
DN: D1.4 (I/O2_2), J2.A7, J2.B7
DP: D1.6 (I/O1_2), J2.A6, J2.B6
EPD_3V3: C7.1, EPD_3V3.TP, EPD_C5.1, J1.15, J1.16, L1.2, Q2.2 (S)
EPD_3V3_C: EPD_3V3_C.TP, Q2.1 (G), R_CL1.2, U2.18 (IO20)
EPD_BUSY: EPD_BUSY.TP, J1.9, U2.26 (IO3)
EPD_CS: D6.2, EPD_CS.TP, J1.12, R9.1, U2.11 (IO10)
EPD_DC: EPD_DC.TP, J1.11, U2.5 (IO5)
EPD_RST: EPD_RST.TP, J1.10, U2.21 (IO23)
FLASH_CS: D9.2, R5.1, U1.1 (!CS), U2.12 (IO11)
GDR: J1.2, Q3.1 (G), R4.1
GND: BOOT_BUTTON.1, BOOT_BUTTON.2, C1.2, C1_BAT.2, C1_BAT1.2, C1_BAT2.2, C2.2, C2_BAT.2, C3.-, C4_USB.2, C5.2, C5_USB.2, C6.2, C7.2, C8.2, C9.2, C10.2, C10_SUPERCAP.1, CHANGE_BUTTON.1, CHANGE_BUTTON.2, C_DELAY.2, D1.2 (GND), D4.1 (K), D6.1, D8.1, D9.1, D10.1, D11.1, D12.1, EPD_C1.2, EPD_C2.2, EPD_C5.2, EPD_C6.2, EPD_C7.2, EPD_C8.2, EPD_C9.2, EPD_C10.2, EPD_C11.2, EPD_C12.2, GND1.TP, GND2.TP, IC1.3 (GND), IC4.2 (VSS), J1.8, J1.17, J1.MP1, J1.MP2, J2.A1, J2.A12, J2.B1, J2.B12, J2.MP1, J2.MP2, J2.MP3, J2.MP4, J3.1, J4.G1 (GND_1), J4.G2 (GND_2), J4.G3 (GND_3), J4.G4 (GND_4), J4.P6 (VSS), MCP73831.2 (VSS), R1_PWRUSB.1, R2.1, R2-USB.2, R2-USB1.1, R2_BAT.1, R4.2, RESET_BUTTON.1, RESET_BUTTON.2, SENSOR2.1 (GND), SENSOR2.5 (SDO), SENSOR2.7 (GND), SJ1.1, U1.4 (GND), U1.9 (EXP), U2.1 (GND), U2.28 (GND), U2.29_1 (GND), U2.29_2 (GND), U2.29_3 (GND), U2.29_4 (GND), U2.29_5 (GND), U2.29_6 (GND), U2.29_7 (GND), U2.29_8 (GND), U2.29_9 (GND), U3.13 (GND), U4.1 (CTG), U4.4 (GND), U4.6 (QSTRT), U4.9 (EP)
GPIO8: R1.2, U2.10 (IO8)
I2C_PW: C1.1, C2.1, R1-PINH.2, R2-PINH.2, SENSOR2.2 (CSB), SENSOR2.6 (VDDIO), SENSOR2.8 (VDD), U2.17 (IO19)
INT_RTC: INT_RTC.TP, R1_PINH1.1, U2.8 (IO0), U3.3 (SQW/!INT)
IO/BOOT: BOOT_BUTTON.3, BOOT_BUTTON.4, C6.1, R_BOOT.1, U2.15 (IO9)
IO/CHANGE: C10.1, CHANGE_BUTTON.3, CHANGE_BUTTON.4, R_CHANGE.1, U2.23 (IO15)
MISO: D12.2, J4.P7 (DAT0), MISO.TP, R8.1, U1.2 (DO(IO1)), U2.27 (IO2)
MOSI: D11.2, J1.14, J4.P3 (CMD), MOSI.TP, R7.1, U1.5 (DI(IO0)), U2.7 (IO7)
unnamed: J2.A5, R2-USB1.2
unnamed: J2.B5, R2-USB.1
unnamed: C1_BAT1.1, D2.1 (CATHODE), IC4.1 (VIN), IC4.3 (CE), Q1.2 (S)
unnamed: C4.1, D3.1 (K), D4.2 (A)
unnamed: CHG_LED.C, R1_BAT.2
unnamed: MCP73831.1 (STAT), R1_BAT.1
unnamed: EPD_C6.1, J1.18
unnamed: MCP73831.5 (PROG), R2_BAT.2
unnamed: EPD_C1.1, J1.4
unnamed: EPD_C2.1, J1.5
unnamed: EPD_C7.1, J1.19
unnamed: EPD_C8.1, J1.20
unnamed: D7.1 (CATHODE), R_CAPACITOR.2
unnamed: EPD_C10.1, J1.22
unnamed: C_DELAY.1, IC1.5 (CT)
unnamed: EPD_C12.1, J1.24
PREVGH: D5.1 (K), EPD_C9.1, J1.21
PREVGL: D3.2 (A), EPD_C11.1, J1.23
RESE: J1.3, Q3.2 (S), R3.1
RESE': R2.2, R3.2, SJ1.2
RESET: C5.1, IC1.1 (VOUT), RESET_BUTTON.3, RESET_BUTTON.4, R_RESET.2, U2.3 (EN)
RTC_RST: U2.16 (IO18), U3.4 (!RST)
RX: RX.TP, U2.24 (RXD0/GPIO17)
SCK: D10.2, J1.13, J4.P5 (CLK), R6.1, SCK.TP, U1.6 (CLK), U2.6 (IO6)
SCL: J3.4, R2-PINH.1, SENSOR2.4 (SCK), U2.20 (IO22), U3.16 (SCL), U4.7 (SCL)
SDA: J3.3, R1-PINH.1, SENSOR2.3 (SDI), U2.19 (IO21), U3.15 (SDA), U4.8 (SDA)
SRC: C4.2, D5.2 (A), L1.1, Q3.3 (D)
SS_SD: D8.2, J4.P2 (CD/DAT3), R10.1, U2.4 (IO4)
TX: TX.TP, U2.25 (TXD0/GPIO16)
USB_D+: D1.1 (I/O1_1), U2.14 (IO13)
USB_D-: D1.3 (I/O2_1), U2.13 (IO12)
VBAT: C2_BAT.1, MCP73831.3 (VBAT), Q1.3 (D), U4.2 (CELL), U4.3 (VDD), VBAT.TP
VBUS: C1_BAT.1, C4_USB.1, C5_USB.1, CHG_LED.A, D1.5 (VBUS), D2.2 (ANODE), MCP73831.4 (VIN), PFMF.050.1.2, Q1.1 (G), R1_PWRUSB.2, VBUS.TP
VRTC: C8.1, C10_SUPERCAP.2, R_CAPACITOR.1, U3.14 (VBAT)
VUSB: J2.A4, J2.A9, J2.B4, J2.B9, PFMF.050.1.1

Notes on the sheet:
USB C connector & ESD protection
LDO Voltage Regulator
SD Card
Display Type Selector
E-Paper Drive Circuit
Li-Po Battery Charging Controller
ESP32 C6
E-Paper Display Header
EPD Power
Environmental Sensor BME688
Voltage Supervisor + Reset & Boot / IO Button
Battery Charge Level
RTC Module DS3231SN
Test Pads
Qwiic / Stemma QT
SPI ESD Protection Lines
External NORFlash64MB
OpenBook Schematic
drawn by: CarmenMurarescu
DeskAssistant v19
3/30/2025 2:00PM
DMG2305UX-7
SD0805S020S1R0
TANT

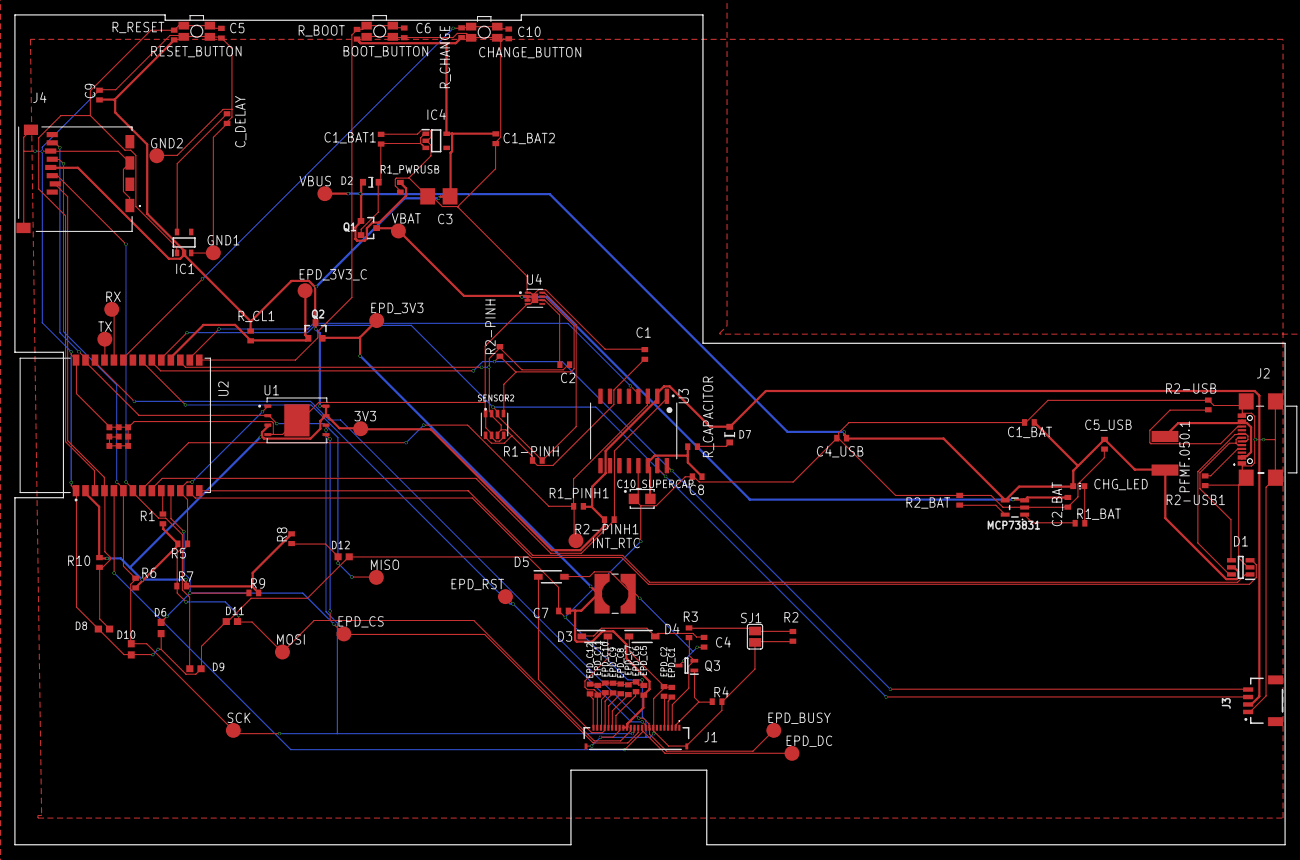
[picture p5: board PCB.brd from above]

Board: 2 copper layers, 170.2 x 111.2 mm, 103 parts (0 on the bottom side), 55 nets.

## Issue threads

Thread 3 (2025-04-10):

Missing component links in BOM

TeodorStamatin, 2025-04-10:
Noticed that not all components listed in the Bill of Materials (BOM) have their corresponding links attached in the README file. (e.g., to Digi-Key, Mouser, or manufacturer pages)

Closed 2025-04-15.

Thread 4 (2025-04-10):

Missing Energy Consumption Calculations

TeodorStamatin, 2025-04-10:
The energy consumption calculations have not been completed for the OpenBook. This step is important to ensure that the device operates efficiently .

Closed 2025-04-15.

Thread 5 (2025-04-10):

Missing Via Stitching Around ESP32 Module

TeodorStamatin, 2025-04-10:
The via stitching around the ESP32 module has not been implemented. Via stitching is essential for ensuring proper signal integrity and grounding, especially for high-speed signals.

Closed 2025-04-16.

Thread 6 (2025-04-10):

Missing 3D Model for SD Card Reader (J4)

TeodorStamatin, 2025-04-10:
The component J4, which should be an SD card reader, is missing a corresponding 3D model in the design. Please ensure that the correct 3D model for the SD card reader is added to the project to ensure accurate visualization and assembly.

Closed 2025-04-14.

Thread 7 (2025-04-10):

Incorrect Naming for BOM and CPL Files

TeodorStamatin, 2025-04-10:
The BOM and CPL files are generated correctly, but their filenames do not follow the correct naming conventions. (currently - [PCB v21.csv] and [PnP_PCB v21_front.csv])

Closed 2025-04-14.

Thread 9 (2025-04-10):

Inconsistency in Label Sizes on Schematic

TeodorStamatin, 2025-04-10:
There is an inconsistency in the label sizes on the schematic. Some labels appear larger than others, which creates visual imbalance. For example, the "I2C_PW" label on the ESP32 module is notably larger than the other labels.

Closed 2025-04-14.

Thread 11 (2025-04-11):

Pour Does Not Fill All Board Areas

TeodorStamatin, 2025-04-11:
The polygon pour for the layer does not cover all areas of the board. This issue can be easily resolved by adding a new polygon pour in the unfilled areas to ensure that the polygon pour fully covers the necessary regions of the board.

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

Closed 2025-04-14.

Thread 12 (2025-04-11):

Silkscreen text for J3 component is not visible

TeodorStamatin, 2025-04-11:
Noticed that the silkscreen text for connector J3 (QWIIC connector) is placed under the component footprint. This makes the label invisible after assembly, as the silkscreen printing interferes with the component placement.

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

Closed 2025-04-14.

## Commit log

2025-04-06 Add files via upload
    Schematicul
    [Schematic_v14.sch]
2025-04-06 Add files via upload
    pcb
    [PCB v21.brd]
2025-04-06 toate fisierele (gerber, pick and place si BOM
    [PCB v21.csv, PnP_PCB v21_front.csv]
2025-04-14 - update dupa issues
    [PCB.brd, Schematic.sch]
2025-04-14 Update and rename PnP_PCB v21_front.csv to PickAndPlace.csv
    [PickAndPlace.csv]
2025-04-14 Update and rename PCB v21.csv to BillOfMaterials.csv
    [BillOfMaterials.csv]
2025-04-14 Am actualizat fisierele la varianta finala

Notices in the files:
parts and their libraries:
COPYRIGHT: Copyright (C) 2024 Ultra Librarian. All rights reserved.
